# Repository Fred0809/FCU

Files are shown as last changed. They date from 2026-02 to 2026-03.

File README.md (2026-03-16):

# FCU
Flight controller unit for up to 6 motors

The board takes 5V from power delivery board mounted below using JST connector alone with battey current and voltage measurements.

Six JST connectors on sides are used to connect to ESCs on each motor. It will use CAN to comunicate between modules.

<p align="center">
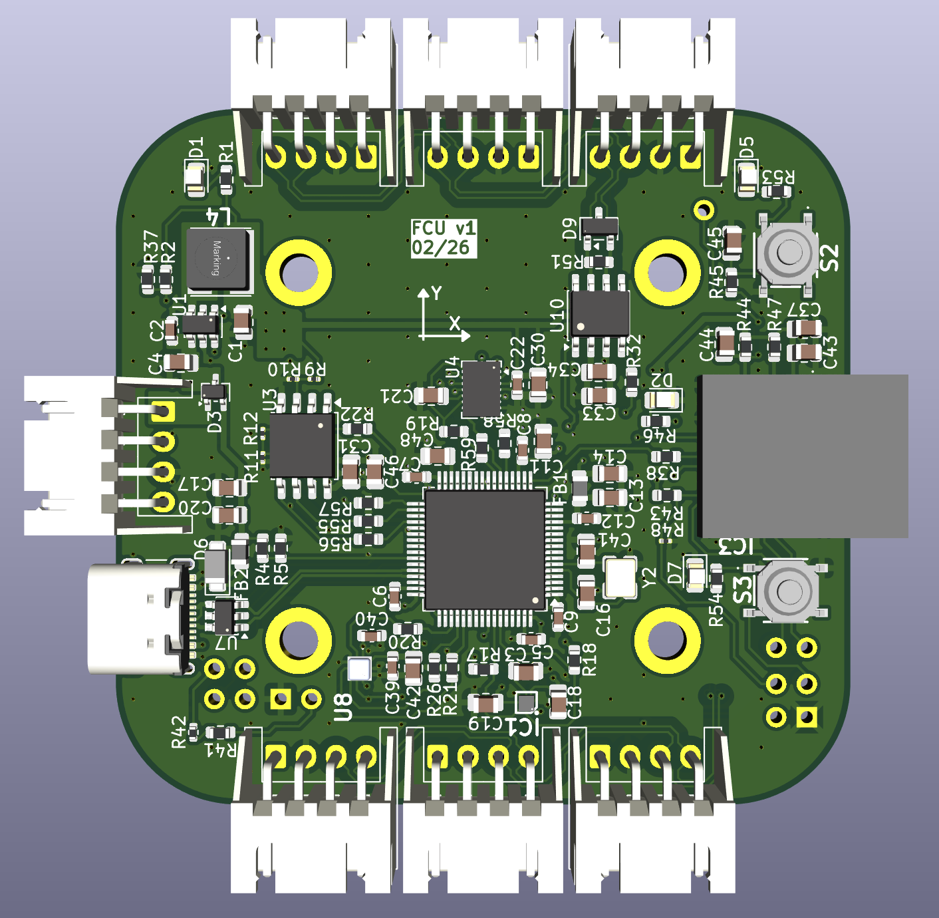
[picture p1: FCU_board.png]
  
</p>

60.8 x 57.6 mm

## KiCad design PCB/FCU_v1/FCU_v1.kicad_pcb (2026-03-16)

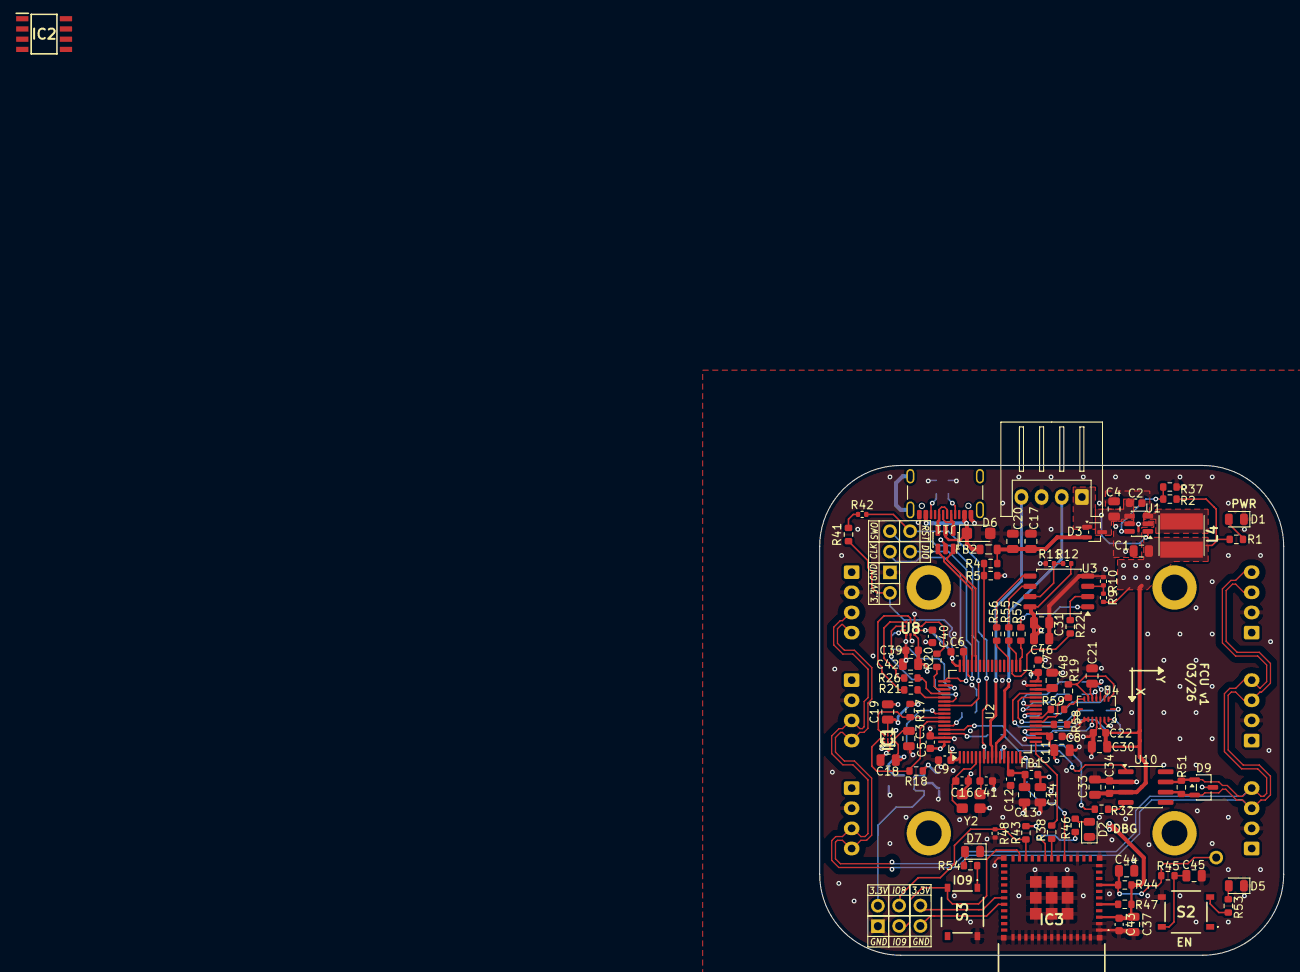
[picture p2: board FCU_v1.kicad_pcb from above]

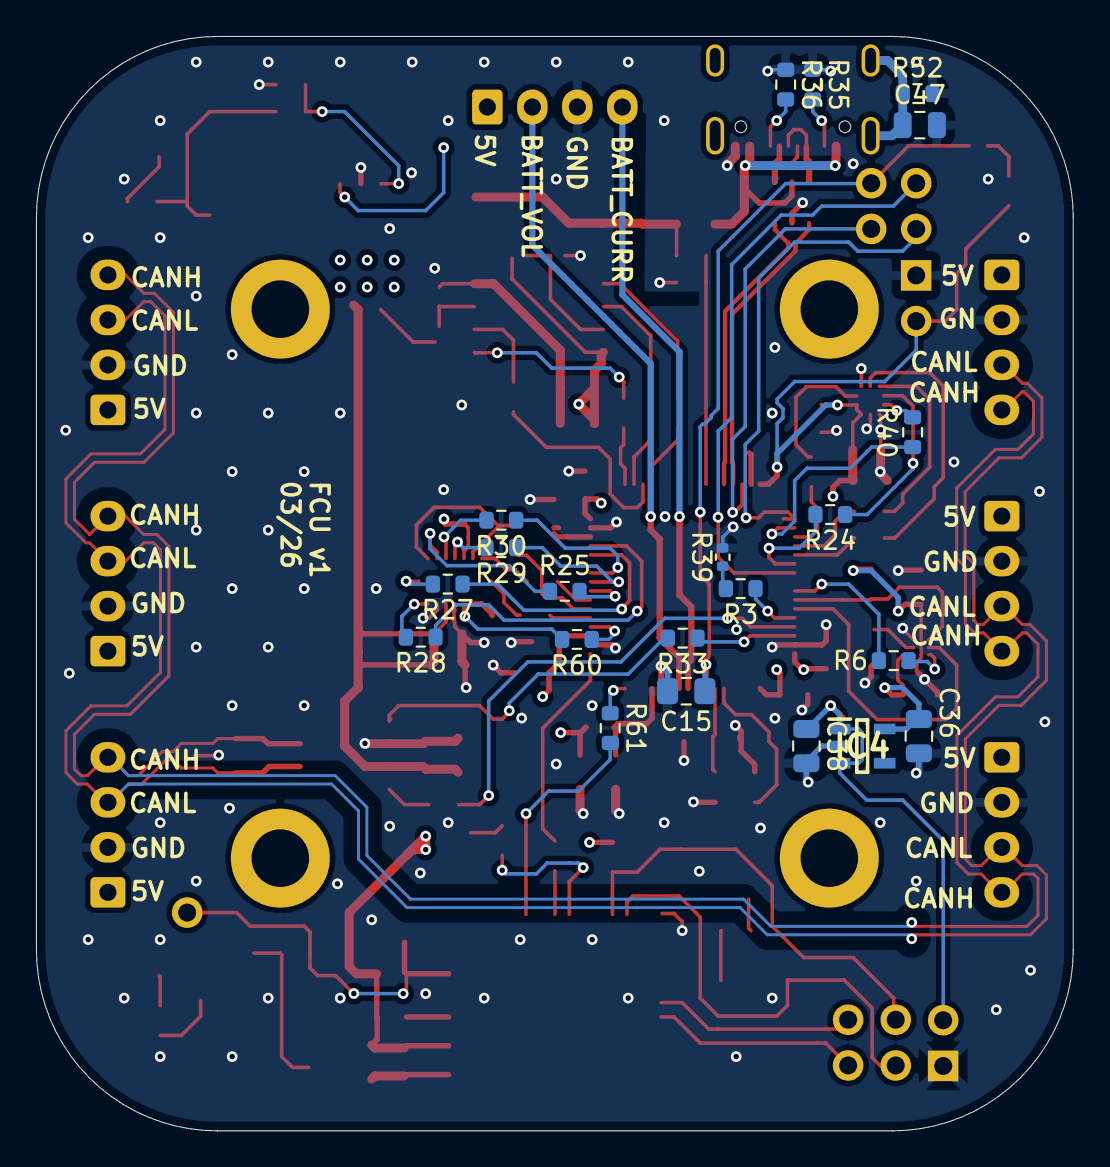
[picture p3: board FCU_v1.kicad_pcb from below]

Board: 4 copper layers, 57.6 x 60.8 mm, 131 parts (21 on the bottom side), 97 nets.

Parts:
C1: 22u/6.3V; C_0805_2012Metric
C2: 100n/10V; C_0603_1608Metric
C3: 2u2/6.3V; C_0805_2012Metric
C4: 10u/10V; C_0805_2012Metric
C5, C6, C7, C8, C9, C22, C39, C40, C43: 100n; C_0603_1608Metric
C11, C37, C46: 10u; C_0805_2012Metric
C12: 10n; C_0603_1608Metric
C13, C14, C38, C44: 1u; C_0805_2012Metric
C15: 100n; C_0805_2012Metric_Pad1.18x1.45mm_HandSolder
C16, C41: 6p8; C_0603_1608Metric
C17: 22u/10V; C_0805_2012Metric
C18, C19, C21, C31, C45: 100n; C_0805_2012Metric
C20: 100n/10V; C_0805_2012Metric
C30, C36, C42: 2u2; C_0805_2012Metric
C33: 1uF; C_0805_2012Metric
C34: 100nF; C_0603_1608Metric
C47: 22u; C_0805_2012Metric
C48: 4u7; C_0805_2012Metric
D1, D2, D5, D7: LED; LED_0805_2012Metric
D3: BAT54CWFILMY; SOT-323_SC-70
D6: SMF54A; D_SMF
D9: ESD2CAN24DBZRQ1; SOT-23-3
FB1: FCM1608KF-601T03; L_0603_1608Metric
FB2: 120R at 100 MHz; L_0805_2012Metric
H1, H2, H3, H4: MountingHole_Pad; MountingHole_3.2mm_M3_ISO14580_Pad
IC1: BMM350; BGA9C40P3X3_128X128X54
IC2: TCAN3414DR; SOIC127P600X175-8N
IC3: ESP32-C3-MINI-1-N4X; ESP32C3MINI1N4X
IC4: TPS7A2018PDBVR; SOT95P280X145-5N
J1, J5, J6, J7, J8, J9, J10: Conn_01x04_Pin; JST_XH_S4B-XH-A_1x04_P2.50mm_Horizontal
J3, J12, J13, J14, J15, J16: Conn_01x02_Pin; PinHeader_1x02_P2.54mm_Vertical
J11: USB_C_Receptacle_USB2.0_16P; USB_C_Receptacle_GCT_USB4105-xx-A_16P_TopMnt_Horizontal
J17: Conn_01x01_Pin; PinHeader_1x01_P2.54mm_Vertical
L4: 744042001; WE-TPC_4818_482892
R1: 2k; R_0603_1608Metric
R2: 450k; R_0603_1608Metric
R3, R41, R43, R44, R45, R47: 10k; R_0603_1608Metric
R4: 33k; R_0603_1608Metric
R5: 82k; R_0603_1608Metric
R6, R19, R20, R21, R22, R24, R25, R26, R27, R28, R29, R30, R40, R55, R56, R57, R58, R59, R60, R61: 33R; R_0603_1608Metric
R9, R10, R11, R12, R39, R42, R48: DNP; R_0402_1005Metric
R17, R18: 4.7k; R_0603_1608Metric
R32, R33: 22Ω; R_0603_1608Metric
R35, R36, R52: 5k1; R_0603_1608Metric
R37: 100k; R_0603_1608Metric
R38, R46, R53, R54: 4k7; R_0603_1608Metric
R51: 120R; R_0603_1608Metric
S2, S3: PTS526SM15SMTR2_LFS; PTS526SM15SMTR2LFS
U1: TPS62A02APDDCR; SOT-23-6
U2: STM32F412RETx; LQFP-64_10x10mm_P0.5mm
U3: W25Q128JVSIM; SOIC-8_5.3x5.3mm_P1.27mm
U4: BMI088; Bosch_LGA-16_4.5x3mm_P0.5mm_LayoutBorder7x1y_ClockwisePinNu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
U7: USBLC6-2SC6; SOT-23-6
U8: BMP581
U10: SN65HVD232; SOIC-8_3.9x4.9mm_P1.27mm
Y2: 24MHz; Crystal_SMD_3225-4Pin_3.2x2.5mm

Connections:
+3.3VA: C12.1, C13.1, FB1.1, U2.13 (VDDA)
+5V: D3.1, J1.1, J5.1, J6.1, J7.1, J8.1, J9.1, J10.1
+5V_FCU: C2.1, C4.1, D3.3, U1.1 (EN), U1.4 (VIN)
+VBUS: C17.1, C20.1, D3.2, FB2.2, R4.2
/D+: J11.A6 (D+), J11.B6 (D+), U7.6 (I/O1)
/D-: J11.A7 (D-), J11.B7 (D-), U7.4 (I/O2)
/ESP/USART2_RX_ESP: IC3.18 (IO4), R38.1
/IMU/ACCE1_INT: R27.2, U4.16 (INT1)
/IMU/ACCE2_INT: R28.2, U4.1 (INT2)
/IMU/BAR_INT: R40.2, U8.7 (INT)
/IMU/CRST_MAG: C3.1, IC1.C2 (CRST)
/IMU/GYRO1_INT: R29.2, U4.12 (INT3)
/IMU/GYRO2_INT: R30.2, U4.13 (INT4)
/IMU/MAG_INT: IC1.A1 (INT), R6.2
/IMU/SPI1_MISO_ACCE: R19.2, U4.10 (SDO2), U4.15 (SDO1)
/IMU/SPI3_MISO_BAR: R26.1, U8.5 (SDO)
/IMU/VDD_BAR: C18.1, C36.1, IC1.C1 (VDD), IC4.5 (OUT)
/MCU/CAN_TX_STM: R33.1, U2.62 (PB9)
/MCU/CSB_ACCE_STM: R25.2, U2.24 (PC4)
/MCU/CS_BARO_STM: R24.2, U2.54 (PD2)
/MCU/CS_GYRO_STM: R60.1, U2.20 (PA4)
/MCU/CS_MEMO_STM: R57.1, U2.33 (PB12)
/MCU/SPI1_MOSI_STM: R59.1, U2.23 (PA7)
/MCU/SPI1_SCK_STM: R58.1, U2.21 (PA5)
/MCU/SPI2_MOSI_STM: R56.1, U2.36 (PB15)
/MCU/SPI2_SCK_STM: R55.1, U2.34 (PB13)
/MCU/SPI3_MOSI_STM: R21.2, U2.53 (PC12)
/MCU/SPI3_SCK_STM: R20.2, U2.51 (PC10)
/MCU/USART2_TX_STM: R61.1, U2.16 (PA2)
/MCU/VCAP: C48.1, U2.30 (VCAP_1)
/SW_TPS: L4.1, U1.3 (SW)
/USB_VBUS: D6.1 (A1), FB2.1, J11.A4 (VBUS), J11.A9 (VBUS), J11.B4 (VBUS), J11.B9 (VBUS), U7.5 (VBUS)
BAT_CURR: J1.4, U2.9 (PC1)
BAT_VOL: J1.2, U2.10 (PC2)
BOOT: R3.1, U2.60 (BOOT0)
CAN+: D9.1 (K), J5.4, J6.4, J7.4, J8.4, J9.4, J10.4, R51.2, U10.7 (CANH)
CAN-: D9.2 (K), J5.3, J6.3, J7.3, J8.3, J9.3, J10.3, R51.1, U10.6 (CANL)
CAN_RX: R32.1, U2.61 (PB8)
CAN_TX: R33.2, U10.1 (D)
CS_ACCE: R25.1, U4.14 (~CSB1)
CS_BARO: R24.1, U8.6 (CSB)
CS_GYRO: R60.2, U4.5 (~CSB2)
CS_MEMO: R57.2, U3.1 (~CS)
ESP_EN: C44.1, IC3.8 (EN), J17.1, R44.1, R45.2
ESP_GPIO2: IC3.5 (IO2), R47.1
ESP_GPIO8: IC3.22 (IO8), J16.1, R43.1, R48.1
ESP_GPIO9: IC3.23 (IO9), J16.2, S3.3 (NO_1)
GND: C1.2, C2.2, C3.2, C4.2, C5.2, C6.2, C7.2, C8.2, C9.2, C11.2, C12.2, C13.2, C14.2, C15.2, C16.1, C17.2, C18.2, C19.2, C20.2, C21.2, C22.2, C30.2, C31.2, C33.2, C34.2, C36.2, C37.2, C38.2, C39.2, C40.2, C41.1, C42.2, C43.2, C44.2, C45.2, C46.2, C47.2, C48.2, D1.1 (K), D2.1 (K), D5.1 (K), D6.2 (A2), D7.1 (K), D9.3 (A), IC1.B1 (GND), IC1.B2 (ADSEL), IC1.C3 (BYPASS), IC3.1 (GND), IC3.2 (GND_2), IC3.11 (GND_3), IC3.14 (GND_4), IC3.36 (GND_5), IC3.37 (GND_6), IC3.38 (GND_7), IC3.39 (GND_8), IC3.40 (GND_9), IC3.41 (GND_10), IC3.42 (GND_11), IC3.43 (GND_12), IC3.44 (GND_13), IC3.45 (GND_14), IC3.46 (GND_15), IC3.47 (GND_16), IC3.48 (GND_17), IC3.49 (GND_18), IC3.50 (GND_19), IC3.51 (GND_20), IC3.52 (GND_21), IC3.53 (GND_22), IC3.54 (GND_23), IC3.55 (GND_24), IC3.56 (GND_25), IC3.57 (GND_26), IC3.58 (GND_27), IC3.59 (GND_28), IC3.60 (GND_29), IC3.61 (GND_30), IC4.2 (GND), J1.3, J3.2, J5.2, J6.2, J7.2, J8.2, J9.2, J10.2, J11.A1 (GND), J11.A12 (GND), J11.B1 (GND), J11.B12 (GND), J14.2, R5.1, R10.1, R11.1, R35.1, R36.1, R37.2, R39.2, R48.2, R52.2, S2.4 (NO_2), S3.2 (COM_2), U1.2 (GND), U1.5 (PG), U2.12 (VSSA), U2.18 (VSS), U2.31 (VSS), U2.47 (VSS), U2.63 (VSS), U3.4 (GND), U4.2 (GNDA), U4.4 (GNDA), U4.6 (GNDIO), U4.7 (PS), U7.2 (GND), U8.3 (VSS), U8.8 (VSS), U8.9 (VSS), U10.2 (GND), Y2.2, Y2.4
I2C_SCL: IC1.A3 (SCK), R17.2, U2.58 (PB6)
I2C_SDA: IC1.A2 (SDA), R18.2, U2.59 (PB7)
INT_ACCE1: R27.1, U2.28 (PB2)
INT_ACCE2: R28.1, U2.29 (PB10)
INT_BARO: R40.1, U2.50 (PA15)
INT_GYRO1: R29.1, U2.25 (PC5)
INT_GYRO2: R30.1, U2.26 (PB0)
INT_MAG: R6.1, U2.57 (PB5)
NRST: C15.1, J13.1, R42.2, U2.7 (NRST)
unnamed: D1.2 (A), R1.2
unnamed: D2.2 (A), R46.2
unnamed: D5.2 (A), R53.2
unnamed: D7.2 (A), R54.2
unnamed: IC3.19 (IO5), R46.1
unnamed: J11.A5 (CC1), R36.2
unnamed: J11.B5 (CC2), R35.2
unnamed: C47.1, J11.S1 (SHIELD), R52.1
unnamed: R3.2, R39.1
unnamed: R41.2, R42.1
unnamed: C45.1, R45.1, S2.2 (COM_2)
unnamed: R53.1, S2.3 (NO_1)
unnamed: R54.1, S3.1 (COM_1)
unnamed: R2.2, R37.1, U1.6 (FB)
unnamed: R22.2, U3.2 (DO/IO_{1})
unnamed: R11.2, R12.1, U3.7 (~HOLD/~RESET/IO_{3})
unnamed: R9.1, R10.2, U3.3 (~WP/IO_{2})
unnamed: R32.2, U10.4 (R)
OSC_IN: C16.2, U2.5 (PH0), Y2.3
OSC_OUT: C41.2, U2.6 (PH1), Y2.1
SPI1_MISO: R19.1, U2.22 (PA6)
SPI1_MOSI: R59.2, U4.9 (SDI/SDA)
SPI1_SCK: R58.2, U4.8 (SCK/SCL)
SPI2_MISO: R22.1, U2.35 (PB14)
SPI2_MOSI: R56.2, U3.5 (DI/IO_{0})
SPI2_SCK: R55.2, U3.6 (CLK)
SPI3_MISO: R26.2, U2.52 (PC11)
SPI3_MOSI: R21.1, U8.4 (SDI)
SPI3_SCK: R20.1, U8.2 (SCK)
STM_VDD: C1.1, C5.1, C6.1, C7.1, C8.1, C9.1, C11.1, C14.1, C19.1, C21.1, C22.1, C30.1, C31.1, C33.1, C34.1, C37.1, C38.1, C39.1, C40.1, C42.1, C43.1, C46.1, FB1.2, IC1.B3 (VDDIO), IC3.3 (3V3), IC4.1 (IN), IC4.3 (EN), J3.1, J14.1, L4.2, R1.1, R2.1, R9.2, R12.2, R17.1, R18.1, R41.1, R43.2, R44.2, R47.2, U2.1 (VBAT), U2.19 (VDD), U2.32 (VDD), U2.48 (VDD), U2.64 (VDD), U3.8 (VCC), U4.3 (VDD), U4.11 (VDDIO), U8.1 (VDDIO), U8.10 (VDD), U10.3 (VCC)
SWCLK: J12.2, U2.49 (PA14)
SWDIO: J13.2, U2.46 (PA13)
SWO: J12.1, U2.55 (PB3)
UART_RX_ESP_DBG: IC3.30 (RXD0), J15.2
UART_TX_ESP_DBG: IC3.31 (TXD0), J15.1
USART2_RX: R38.2, U2.17 (PA3)
USART2_TX: IC3.16 (IO10), R61.2
USB_D+: U2.45 (PA12), U7.1 (I/O1)
USB_D-: U2.44 (PA11), U7.3 (I/O2)
VBUS_SENS: R4.1, R5.2, U2.42 (PA9)

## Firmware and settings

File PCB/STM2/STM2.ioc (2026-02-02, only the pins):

Mcu.UserName=STM32G473RETx
PA0.GPIO_Label=INT1_GYRO
PA0.Signal=GPXTI0
PA1.GPIO_Label=INT2_ACCEL
PA1.Signal=GPXTI1
PA11.Signal=USB_DM
PA12.Signal=USB_DP
PA13.Signal=SYS_JTMS-SWDIO
PA14.Signal=SYS_JTCK-SWCLK
PA2.GPIO_Label=INT1_ACCEL
PA2.Signal=GPXTI2
PA5.Signal=SPI1_SCK
PA6.Signal=SPI1_MISO
PA7.Signal=SPI1_MOSI
PA9.GPIO_Label=VBUS_SENS
PA9.Signal=GPIO_Input
PB0.GPIO_Label=CSB_MEMO
PB0.Signal=GPIO_Output
PB12.Signal=FDCAN2_RX
PB13.Signal=FDCAN2_TX
PB3.Signal=SYS_JTDO-SWO
PB5.GPIO_Label=GNSS_RST
PB5.Signal=GPIO_Output
PB6.GPIO_Label=GNSS_TX
PB6.Signal=USART1_TX
PB7.GPIO_Label=GNSS_RX
PB7.Signal=USART1_RX
PB8-BOOT0.GPIO_Label=BOOT
PB8-BOOT0.Signal=GPIO_Input
PC0.GPIO_Label=BAT_VOL
PC0.Signal=ADC1_IN6
PC1.GPIO_Label=BAT_CURR
PC1.Signal=ADC2_IN7
PC3.GPIO_Label=INT2_GYRO
PC3.Signal=GPXTI3
PC4.GPIO_Label=CSB_ACCEL
PC4.Signal=GPIO_Output
PC5.GPIO_Label=CSB_GYRO
PC5.Signal=GPIO_Output
PC6.GPIO_Label=MAG_INT
PC6.Signal=GPXTI6
PC7.GPIO_Label=BAR_INT
PC7.Signal=GPXTI7
PC8.Signal=I2C3_SCL
PC9.Signal=I2C3_SDA
PF0-OSC_IN.Signal=RCC_OSC_IN
PF1-OSC_OUT.Signal=RCC_OSC_OUT
PG10-NRST.GPIO_Label=NRST
PG10-NRST.Signal=GPIO_Input

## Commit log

2026-01-31 Add FCU v1 schematic PDF
    Added the initial version of the FCU v1 schematic in PDF format to the PCB directory for documentation and reference.
2026-01-31 Add various hardware datasheets in PDF format
    Added multiple datasheet and schematic PDF files for components including MAX-M10M, SparkFun u-blox GNSS, STM32, BMI088, LIS2MDL, LPS22HH, SN65HVD230, STM32G473CB, TLV755P, TPS62133, and W25Q64JV. Th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
2026-01-31 Add accelerometer and barometer schematics
    Added ACCE.kicad_sch for the BMI088 accelerometer/gyroscope and BAROMETER.kicad_sch for the LPS22HH barometer. Also included related KiCad project, schematic, PCB, and backup files for the FCU_v1 boa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
    [ACCE.kicad_sch, BAROMETER.kicad_sch, FCU_v1.kicad_pcb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]
2026-02-02 Remove obsolete sensor schematic files
    Deleted ACCE.kicad_sch, BAROMETER.kicad_sch, MAGNETOMETER.kicad_sch, and related autosave/untitled files from PCB/FCU_v1. Added a backup zip to FCU_v1-backups. This cleans up unused or migrated schem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
    [ACCE.kicad_sch, BAROMETER.kicad_sch, MAGNETOMETER.kicad_sch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]
2026-02-02 Add FCU block diagram and update PCB layout
    Added FCU.drawio block diagram and new STM/STM2 IOC files. Updated FCU_v1.kicad_pcb with component position changes and connector orientation. Added a new backup ZIP for FCU_v1.
    [FCU_v1.kicad_pcb]
2026-02-02 Update FCU_v1 PCB and add new resistors
    Reworked net assignments and added new nets in FCU_v1.kicad_pcb. Added and repositioned resistors R23 and R28, and updated footprints and net connections. Also updated several backup files and made minor schematic changes in MCU.kicad_sch and PERIPHERALS.kicad_sch.
    [FCU_v1.kicad_pcb, MCU.kicad_sch, PERIPHERALS.kicad_sch]
2026-02-03 Adjust PCB footprint positions and metadata
    Add three FCU_v1 backup archives and apply multiple PCB layout fixes: reposition and reorient many footprints (resistors, capacitors, inductors, diodes, SOT-23, LQFP, LGA, etc.), update pad orientation/rotation entries, and correct numerous fp_line coordinates and UUIDs. Also include small updates to project/prl and PERIPHERALS schematic references. These changes refine component placement and silkscreen/fabrication outlines for the FCU_v1 board.
    [FCU_v1.kicad_pcb, PERIPHERALS.kicad_sch]
2026-02-04 Added next version v2
    Added notes for next version with what needs to be improved or completely fixed. Notes in schematic file
    [FCU_v1.kicad_pcb, FCU_v1.kicad_sch, MCU.kicad_sch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]
2026-02-06 Update PCB footprints, positions and backups
    Remove old FCU_v1 backup zips and add new timestamped backups. Apply extensive edits to PCB/FCU_v1.kicad_pcb: reposition and rotate multiple footprints, fix pad orientations, update silkscreen/fab/crtyd outlines and UUIDs, change some net mappings and sheet/path references, and replace a resistor footprint with a SOT-23-6 ESD device (USBLC6) including updated properties and datasheet. Update related project/schematic files (FCU_v1.kicad_prl, FCU_v1.kicad_sch, PERIPHERALS.kicad_sch) to reflect these changes.
    [FCU_v1.kicad_pcb, FCU_v1.kicad_sch, PERIPHERALS.kicad_sch]
2026-02-17 Layout update
    [FCU_v1.kicad_pcb, MCU.kicad_sch, PERIPHERALS.kicad_sch]
2026-02-20 Schematic update
    [ACCE.kicad_sch, ESP.kicad_sch, FCU_v1.kicad_pcb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]
2026-02-20 Repaired library
    [ESP.kicad_sch, FCU_v1.kicad_pcb, IMU.kicad_sch]
2026-02-23 Components change and layout update
    [ESP.kicad_sch, FCU_v1.kicad_pcb, FCU_v1.kicad_sch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]
2026-02-28 Layout cleanup + PCB view
    [FCU_v1.kicad_pcb]
